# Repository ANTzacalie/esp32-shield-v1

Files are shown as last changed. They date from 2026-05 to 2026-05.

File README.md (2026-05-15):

# ESP32 Shield V1






---

## About the Project

A **student electronics project** — a large, spacious development shield designed to make working with ESP32 reliable, practical, and accessible. Whether you're prototyping, learning, or building something more permanent, this board gives you the room and connectivity to do it right.

The ESP32 Shield V1 breaks out **all useful GPIO pins** (bootstrapping pins like GPIO11 excluded) through both **terminal block connectors** for permanent wiring and **male pin headers** for Dupont jumper wire access. It supports both the **ESP32 DevKit C** and **ESP32-S** variants — both fit into the onboard 2×19 socket pins.

Power is supplied through a modern **USB-C 6-pin connector**, compatible with any USB-C charger or USB-A to USB-C adapter — no more bulky legacy connectors. A **power LED** confirms the board is live at a glance.

---

## Features

-  **USB-C Power Input** — 6-pin USB-C connector; works with any USB-C or USB-A (female-to-USB-C) charger
-  **Full GPIO Breakout** — all useful ESP32 GPIO pins exposed (bootstrapping pins excluded)
-  **Terminal Block Connectors** — for all useful pins, ideal for permanent or semi-permanent wiring
-  **Male Pin Headers** — Dupont-compatible, for quick breadboard or jumper wire access
-  **ESP32 DevKit C & 32S Compatible** — both modules fit the 2×19 socket pin layout
-  **5V Rail up to 1A** — 2 terminal blocks with 5V and GND in 1:1 configuration
-  **5V & 3.3V Header Pins** — 2×4 header for 5V and 3.3V (max 500mA via AMS1117-3.3 regulator)
-  **4×4 GND Header** — dedicated ground header block
-  **Power Indicator LED** — shows board is powered and ready
-  **Big, Spacious Board** — generous layout for comfortable hand soldering and clear wiring

---

## Gallery

<p align="center">
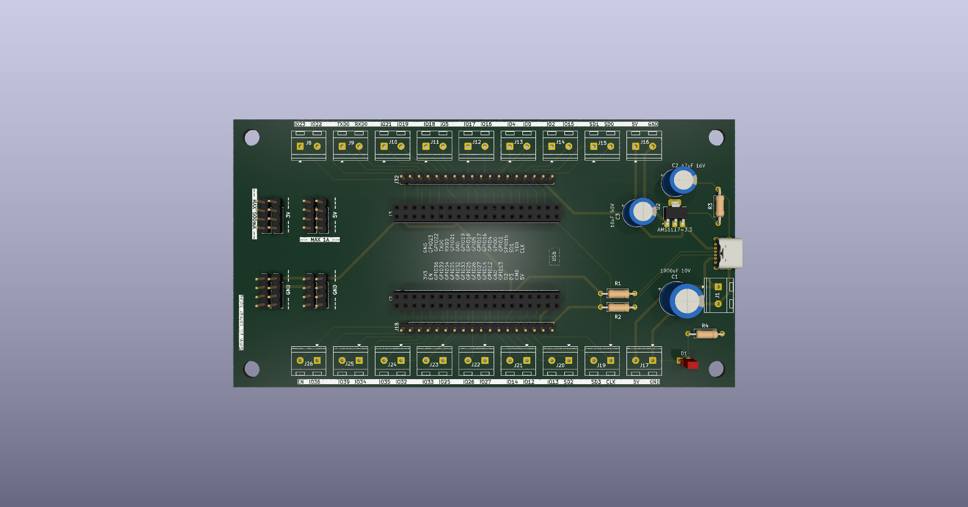
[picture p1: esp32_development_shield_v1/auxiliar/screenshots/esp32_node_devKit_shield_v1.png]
  
  &nbsp;&nbsp;
  
</p>

---

## Documents

| Document | Link |
|---|---|
| PCB Layout | [shield_v1_pcb.pdf](esp32_development_shield_v1/auxiliar/screenshots/shield_v1_pcb.pdf) |
| Schematic | [shield_v1_schematic.pdf](esp32_development_shield_v1/auxiliar/screenshots/shield_v1_schematic.pdf) |

---

## Demo

<p align="center">
  ESP32 Shield V1 Demo
  <!-- If using mp4: see auxiliar/test_video/video.mp4 -->
</p>

---

## Folder Structure

```
esp32-shield-v1/
│
├── auxiliar/
│   ├── compatibility_info/       # Compatibility notes for ESP32 variants
│   ├── screenshots/              # Board photos (photo1–photo4)
│   └── test_video/               # Demo video (video.gif / video.mp4)
│
├── pcb/
│   ├── bom_files/                # 📋 Bill of Materials (BOM)
│   ├── drill_files/              # 🔩 Drill files for PCB fabrication
│   └── gerber_files/             # 📦 Gerber files — send these to your PCB fab
│
└── schematic/
    ├── esp32_node_devkit_shield_v1/   # Main schematic project files
    └── symbols&footprints/            # Custom KiCad symbols and footprints
```

> **PCB fabrication files are located in `/pcb/`:**
> - **`/pcb/gerber_files/`** — Production-ready Gerber files for your PCB manufacturer
> - **`/pcb/drill_files/`** — Drill/Excellon files for hole placement
> - **`/pcb/bom_files/`** — Bill of Materials for component sourcing

---

## Getting Started

1. Clone or download this repository
2. Open the schematic in **KiCad** from `/schematic/esp32_node_devkit_shield_v1/`
3. Review the BOM in `/pcb/bom_files/` and source your components
4. Send the files from `/pcb/gerber_files/` and `/pcb/drill_files/` to your preferred PCB manufacturer
5. Assemble, plug in your ESP32 DevKit C or 32S, connect USB-C power, and build something!

---

## Compatibility

| Module | Fits? |
|---|---|
| ESP32 DevKit C | ✅ Yes |
| ESP32-S (DevKitS) | ✅ Yes |

See `/auxiliar/compatibility_info/` for detailed notes.

---

## Power Specifications

| Rail | Max Current | Connector Type |
|---|---|---|
| 5V | 1A | 2× Terminal Block (5V + GND) |
| 5V | — | 2×4 Pin Header |
| 3.3V | 500mA | 2×4 Pin Header (AMS1117-3.3) |
| GND | — | 4×4 Pin Header |

---

## License

This project is open source. Feel free to use, modify, and build upon it for personal and educational purposes.

---

*Made with monster-energy and a soldering iron — student electronics project*

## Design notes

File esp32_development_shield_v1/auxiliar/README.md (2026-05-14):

///////////////// Components Used /////////////////

- 1 x AMS1117 3.3 Linear Voltage Regulator;
- 18 x Screw_Terminal_Block_1x02_P5mm or 2 x 1x18_P5mm;
- 1 x Screw_Terminal_Block_1x02_P5mm;
- 8 x 1x04 Pin_Header_P2.54mm;
- 2 x 1x18 Pin_Header_P2.54mm;
- 2 x 02x19 or 02x20(break one off) Pin_Socket_P2.54mm;
- 1 x 6 pin USB-C Power Conector;
- 2 x 5.1k resistors;
- 1 x 330 ohm resistor;
- 1 x 220 ohm resistor;
- 1 x 50V 10uF capacitor;
- 1 x 16V 47uF capacitor;
- 1 x 10V 1000uF capacitor;

///////////////// Components Used /////////////////

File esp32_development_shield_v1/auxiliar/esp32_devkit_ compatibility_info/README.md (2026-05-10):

Shield V1 is compatible with the fallowing ESP32 Devkits:
    - ESP32NodeMCU32S 38 Pin variant, smaller PCB.
        by size: W = 22.9mm between pin barrets
    - ESP32NodeMCU DevKit-C 38 Pin variant, bigger PCB with corner holes.
        by size: W = 25.4mm between pin barrets

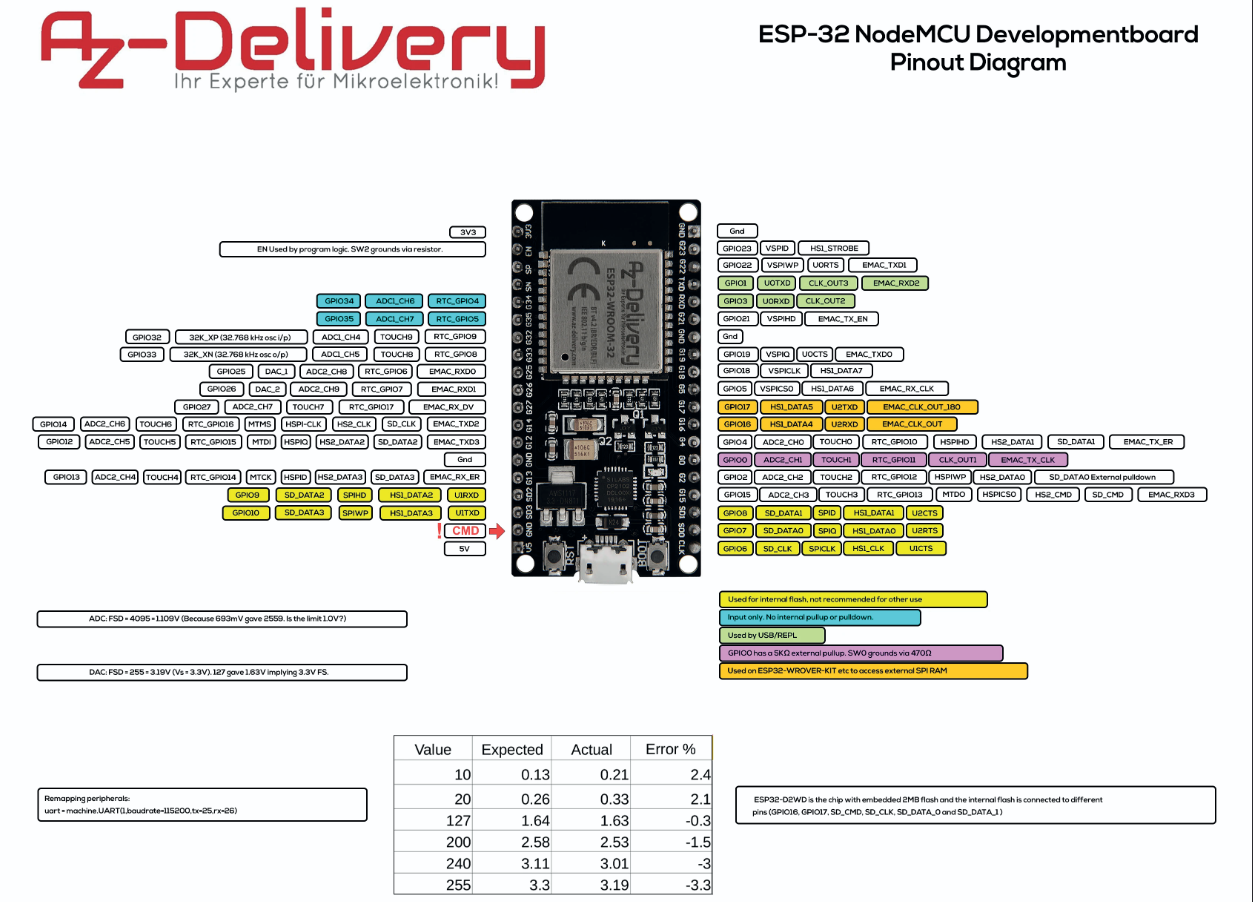
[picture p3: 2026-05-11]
esp32_development_shield_v1/auxiliar/esp32_devkit_ compatibility_info/ESP32-NodeMCU-DevKitM-C.png

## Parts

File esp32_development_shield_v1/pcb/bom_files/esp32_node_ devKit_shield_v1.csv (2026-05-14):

Reference | Qty | Value | DNP | Exclude from BOM | Exclude from Board | Footprint | Datasheet | Description
C1 | 1 | 1000uF 10V |  |  |  | Capacitor_THT:CP_Radial_D10.0mm_P5.00mm |  | Polarized capacitor
C2 | 1 | 47uF 16V |  |  |  | Capacitor_THT:CP_Radial_D8.0mm_P5.00mm |  | Polarized capacitor
C3 | 1 | 10uF 50V |  |  |  | Capacitor_THT:CP_Radial_D8.0mm_P5.00mm |  | Polarized capacitor
D1 | 1 | LED |  |  |  | LED_THT:LED_Rectangular_W3.0mm_H2.0mm |  | Light emitting diode
J1,J8,J9,J10,J11,J12,J13,J14,J15,J16,J17,J19,J20,J21,J22,J23,J24,J25,J26 | 19 | Screw_Terminal_01x02 |  |  |  | TerminalBlock_RND:TerminalBlock_RND_205-00232_1x02_P5.08mm_Horizontal |  | Generic screw terminal, single row, 01x02, script generated (kicad-library-utils/schlib/autogen/connector/)
J2,J3 | 2 | Conn_02x19_Odd_Even |  |  |  | Connector_PinSocket_2.54mm:PinSocket_2x19_P2.54mm_Vertical |  | Generic connector, double row, 02x19, odd/even pin numbering scheme (row 1 odd numbers, row 2 even numbers), script generated (kicad-library-utils/schlib/autogen/connector/)
J4,J5,J6,J7,J27,J28,J29,J30 | 8 | Conn_01x04 |  |  |  | Connector_PinHeader_2.54mm:PinHeader_1x04_P2.54mm_Vertical |  | Generic connector, single row, 01x04, script generated (kicad-library-utils/schlib/autogen/connector/)
J18,J32 | 2 | Conn_01x18_Pin |  |  |  | Connector_PinHeader_2.54mm:PinHeader_1x18_P2.54mm_Vertical |  | Generic connector, single row, 01x18, script generated
J31 | 1 | USB_C_Receptacle_PowerOnly_6P |  |  |  | Connector_USB:USB_C_Receptacle_GCT_USB4125-xx-x_6P_TopMnt_Horizontal | https://www.usb.org/sites/default/files/documents/usb_type-c.zip | USB Power-Only 6P Type-C Receptacle connector
R1,R2 | 2 | 5.1k |  |  |  | Resistor_THT:R_Axial_DIN0207_L6.3mm_D2.5mm_P10.16mm_Horizontal |  | Resistor
R3 | 1 | 330 |  |  |  | Resistor_THT:R_Axial_DIN0207_L6.3mm_D2.5mm_P10.16mm_Horizontal |  | Resistor
R4 | 1 | 220 |  |  |  | Resistor_THT:R_Axial_DIN0207_L6.3mm_D2.5mm_P10.16mm_Horizontal |  | Resistor
U2 | 1 | AMS1117-3.3 |  |  |  | Package_TO_SOT_SMD:SOT-223-3_TabPin2 | http://www.advanced-monolithic.com/pdf/ds1117.pdf | 1A Low Dropout regulator, positive, 3.3V fixed output, SOT-223

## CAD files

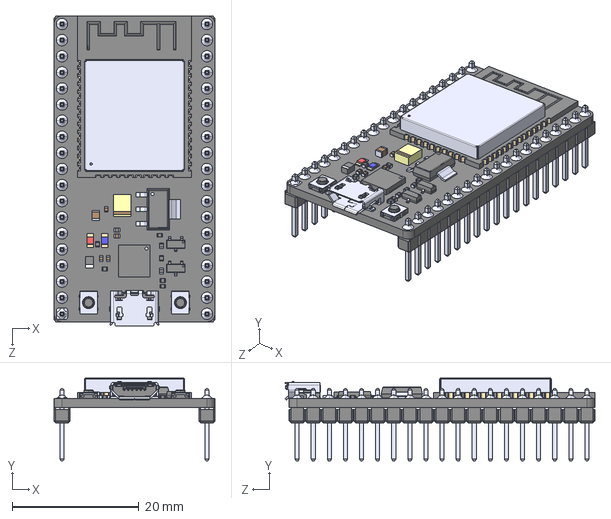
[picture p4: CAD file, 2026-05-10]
esp32_development_shield_v1/schematic/symbols&footprints/ESP-NODEMCU-ESP32S/NODEMCU-ESP32S--3DModel-STEP-269445.STEP
25.4 x 13.0 x 48.9 mm

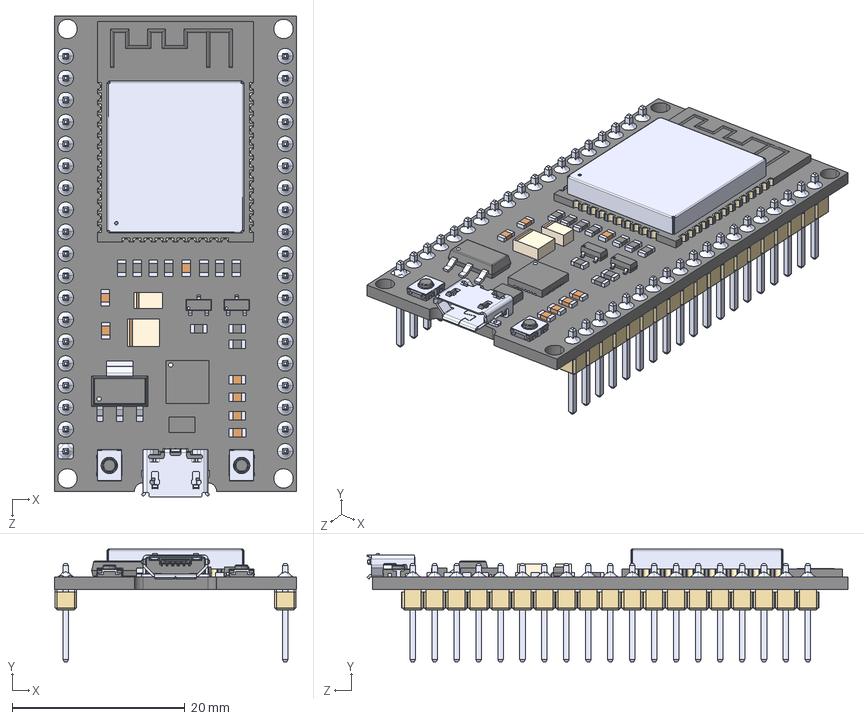
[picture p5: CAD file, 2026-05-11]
esp32_development_shield_v1/schematic/symbols&footprints/ESP32_NODEMCU_AZ-Delivery/ESP32_NODEMCU.step
28.0 x 13.0 x 55.7 mm
board
header
header_2nd
ESP32
micro usb
button x 2
AMS1117-3.3
CP2102
sot-23-3 x 2
other^ESP32 NodeMCU

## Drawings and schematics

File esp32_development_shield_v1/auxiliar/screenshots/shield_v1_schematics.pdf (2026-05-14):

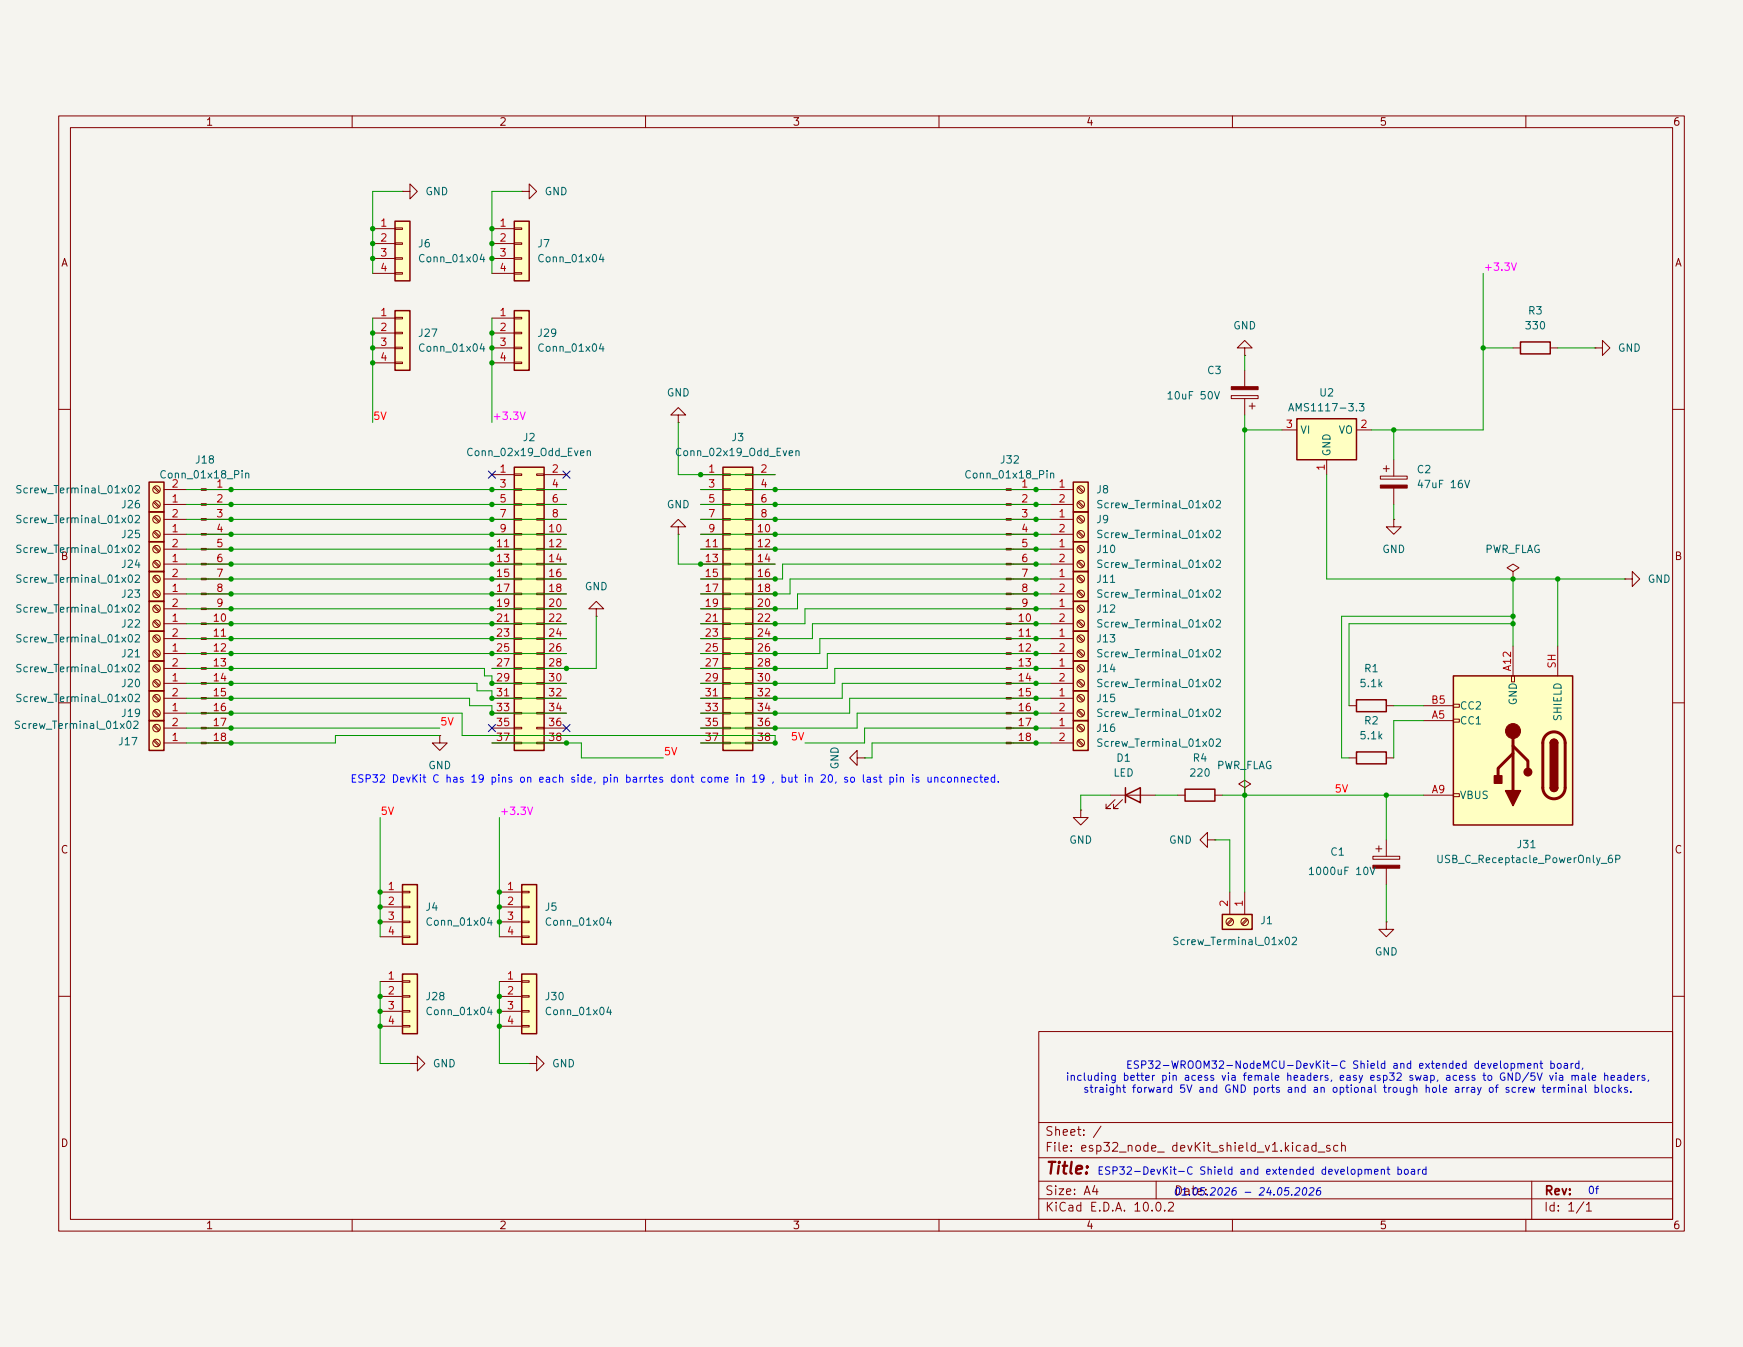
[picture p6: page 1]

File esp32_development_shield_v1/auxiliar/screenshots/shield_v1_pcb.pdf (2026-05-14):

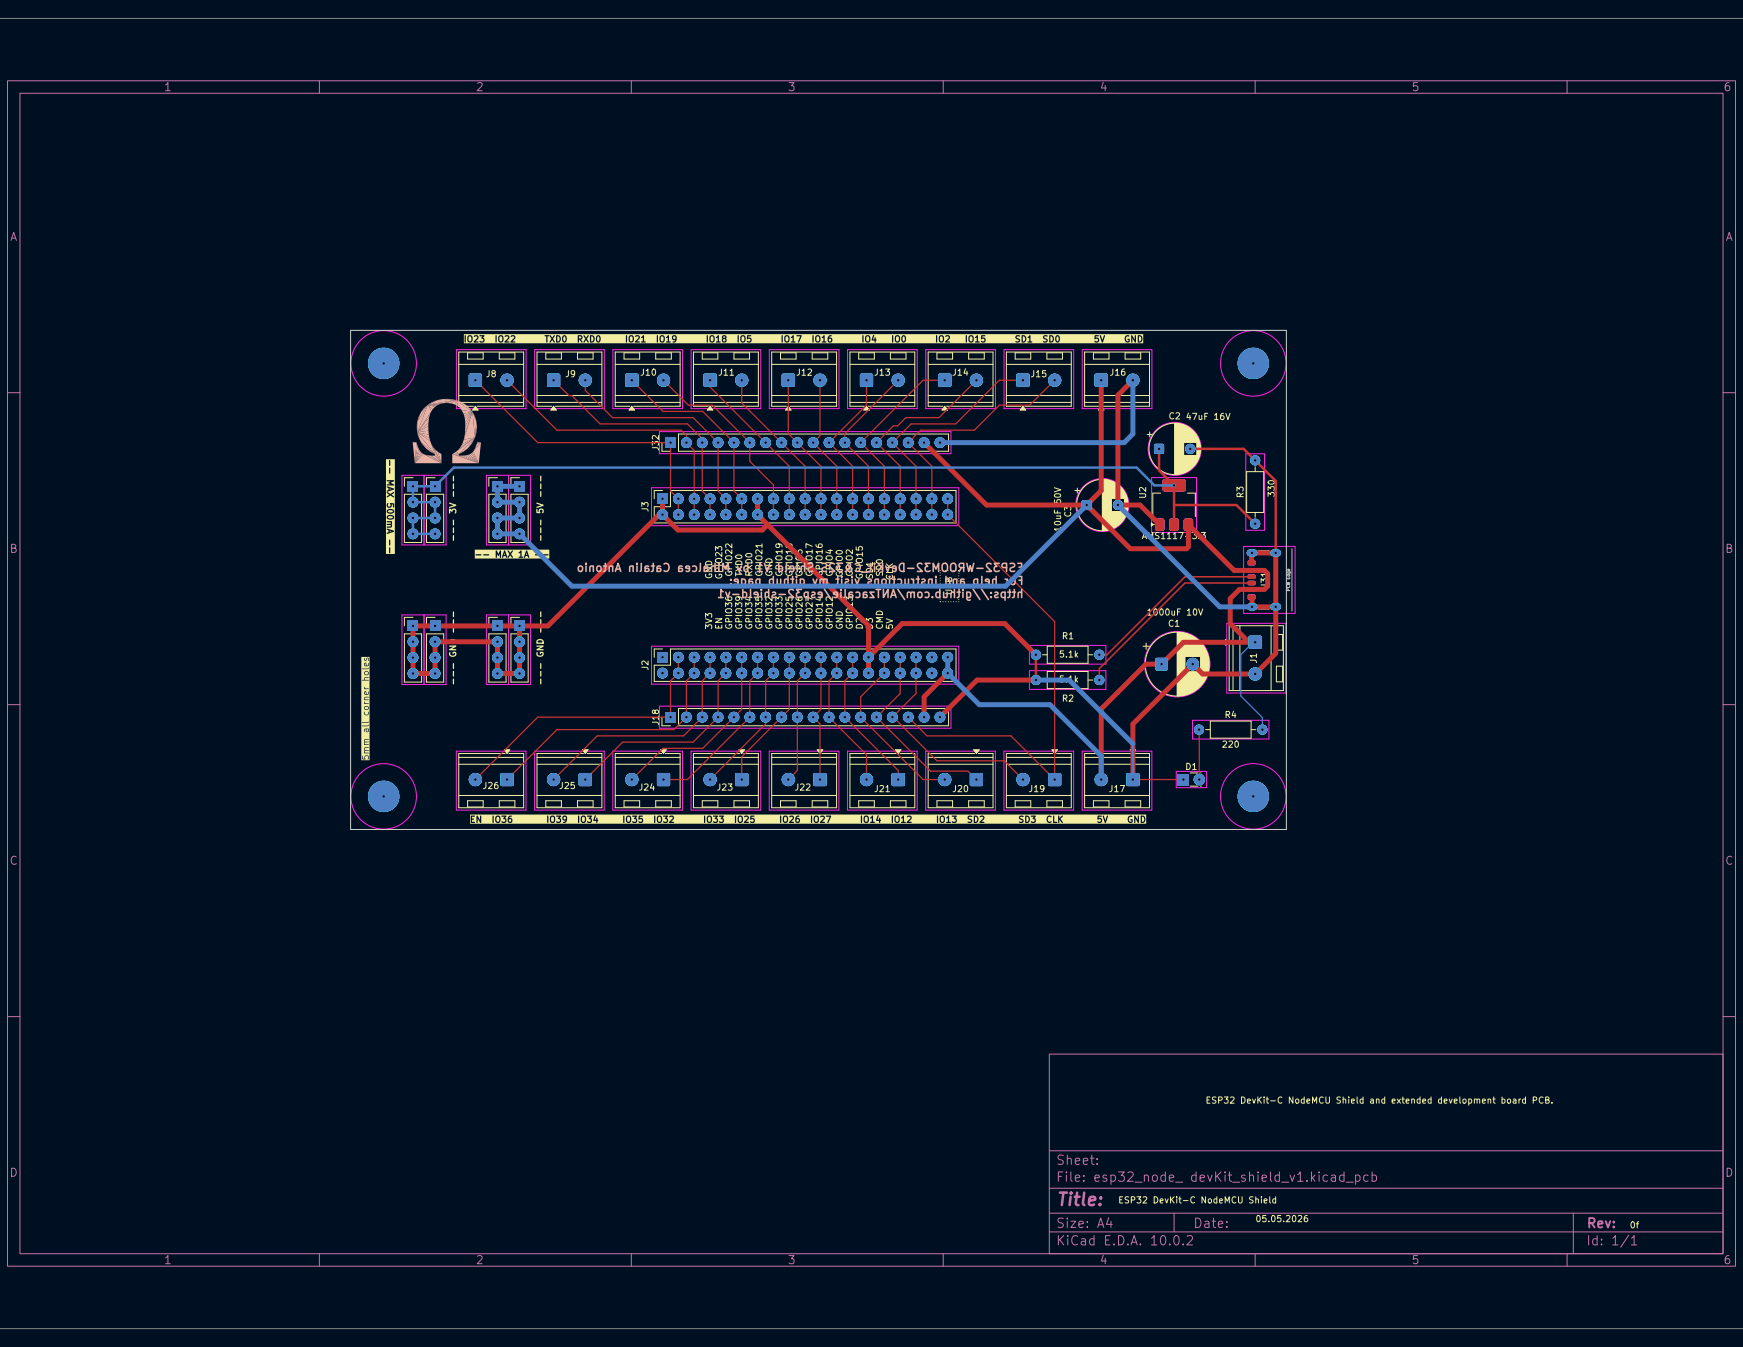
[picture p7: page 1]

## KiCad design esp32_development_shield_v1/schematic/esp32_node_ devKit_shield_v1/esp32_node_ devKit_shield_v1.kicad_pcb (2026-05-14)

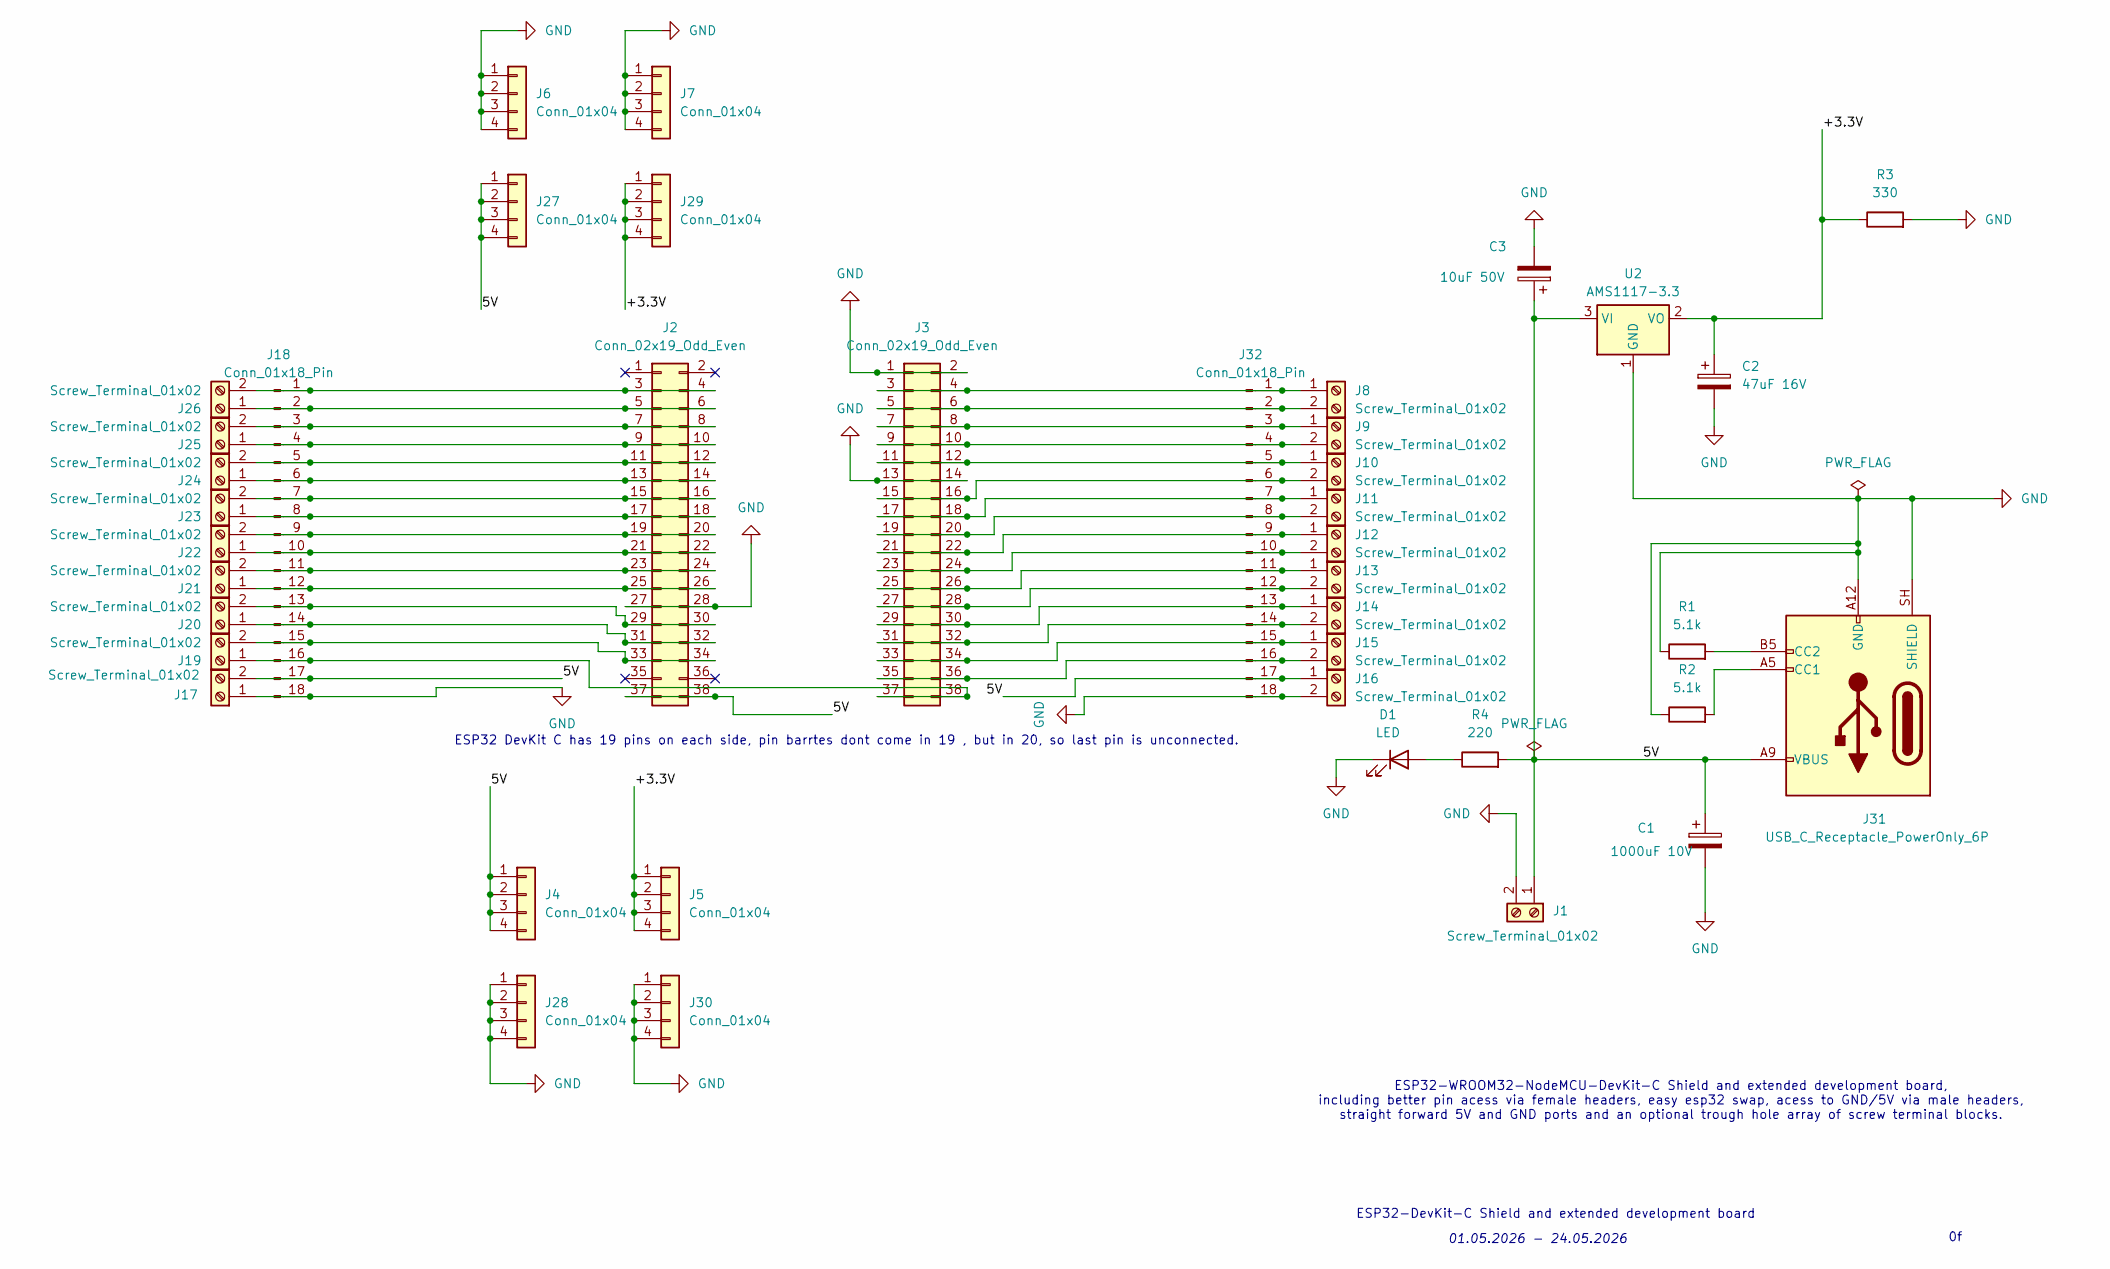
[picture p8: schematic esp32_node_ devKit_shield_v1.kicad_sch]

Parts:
C1: 1000uF 10V; CP_Radial_D10.0mm_P5.00mm
C2: 47uF 16V; CP_Radial_D8.0mm_P5.00mm
C3: 10uF 50V; CP_Radial_D8.0mm_P5.00mm
D1: LED; LED_Rectangular_W3.0mm_H2.0mm
J1, J8, J9, J10, J11, J12, J13, J14, J15, J16, J17, J19, J20, J21, J22, J23, J24, J25, J26: Screw_Terminal_01x02; TerminalBlock_RND_205-00232_1x02_P5.08mm_Horizontal
J2, J3: Conn_02x19_Odd_Even; PinSocket_2x19_P2.54mm_Vertical
J4, J5, J6, J7, J27, J28, J29, J30: Conn_01x04; PinHeader_1x04_P2.54mm_Vertical
J18, J32: Conn_01x18_Pin; PinHeader_1x18_P2.54mm_Vertical
J31: USB_C_Receptacle_PowerOnly_6P; USB_C_Receptacle_GCT_USB4125-xx-x_6P_TopMnt_Horizontal
R1, R2: 5.1k; R_Axial_DIN0207_L6.3mm_D2.5mm_P10.16mm_Horizontal
R3: 330; R_Axial_DIN0207_L6.3mm_D2.5mm_P10.16mm_Horizontal
R4: 220; R_Axial_DIN0207_L6.3mm_D2.5mm_P10.16mm_Horizontal
U2: AMS1117-3.3; SOT-223-3_TabPin2

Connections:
/5V: C1.1, C3.1, J1.1, J2.37, J2.38, J4.1, J4.2, J4.3, J4.4, J16.1, J17.2, J18.17, J27.1, J27.2, J27.3, J27.4, J31.A9 (VBUS), J31.B9 (VBUS), J32.17, R4.2, U2.3 (VI)
/+3.3V: C2.1, J5.1, J5.2, J5.3, J5.4, J29.1, J29.2, J29.3, J29.4, R3.1, U2.2 (VO)
GND: C1.2, C2.2, C3.2, D1.1 (K), J1.2, J2.27, J2.28, J3.1, J3.2, J3.13, J3.14, J6.1, J6.2, J6.3, J6.4, J7.1, J7.2, J7.3, J7.4, J16.2, J17.1, J18.18, J28.1, J28.2, J28.3, J28.4, J30.1, J30.2, J30.3, J30.4, J31.A12 (GND), J31.B12 (GND), J31.SH (SHIELD), J32.18, R1.1, R2.1, R3.2, U2.1 (GND)
unnamed: D1.2 (A), R4.1
unnamed: J3.3, J3.4, J8.1, J32.1
unnamed: J3.5, J3.6, J8.2, J32.2
unnamed: J3.7, J3.8, J9.1, J32.3
unnamed: J3.9, J3.10, J9.2, J32.4
unnamed: J3.11, J3.12, J10.1, J32.5
unnamed: J3.15, J3.16, J10.2, J32.6
unnamed: J3.17, J3.18, J11.1, J32.7
unnamed: J3.19, J3.20, J11.2, J32.8
unnamed: J3.21, J3.22, J12.1, J32.9
unnamed: J3.23, J3.24, J12.2, J32.10
unnamed: J3.25, J3.26, J13.1, J32.11
unnamed: J3.27, J3.28, J13.2, J32.12
unnamed: J3.29, J3.30, J14.1, J32.13
unnamed: J3.31, J3.32, J14.2, J32.14
unnamed: J3.33, J3.34, J15.1, J32.15
unnamed: J3.35, J3.36, J15.2, J32.16
unnamed: J2.3, J2.4, J18.1, J26.2
unnamed: J2.5, J2.6, J18.2, J26.1
unnamed: J2.7, J2.8, J18.3, J25.2
unnamed: J2.9, J2.10, J18.4, J25.1
unnamed: J2.11, J2.12, J18.5, J24.2
unnamed: J2.13, J2.14, J18.6, J24.1
unnamed: J2.15, J2.16, J18.7, J23.2
unnamed: J2.17, J2.18, J18.8, J23.1
unnamed: J2.19, J2.20, J18.9, J22.2
unnamed: J2.21, J2.22, J18.10, J22.1
unnamed: J2.23, J2.24, J18.11, J21.2
unnamed: J2.25, J2.26, J18.12, J21.1
unnamed: J2.29, J2.30, J18.13, J20.2
unnamed: J2.31, J2.32, J18.14, J20.1
unnamed: J2.33, J2.34, J18.15, J19.2
unnamed: J3.37, J3.38, J18.16, J19.1
unnamed: J31.A5 (CC1), R2.2
unnamed: J31.B5 (CC2), R1.2

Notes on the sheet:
ESP32-DevKit-C Shield and extended development board
ESP32-WROOM32-NodeMCU-DevKit-C Shield and extended development board, including better pin acess via female headers, easy esp32 swap, acess to GND/5V via male headers, straight forward 5V and GND ports and an optional trough hole array of screw terminal blocks.
ESP32 DevKit C has 19 pins on each side, pin barrtes dont come in 19 , but in 20, so last pin is unconnected.
01.05.2026 - 24.05.2026

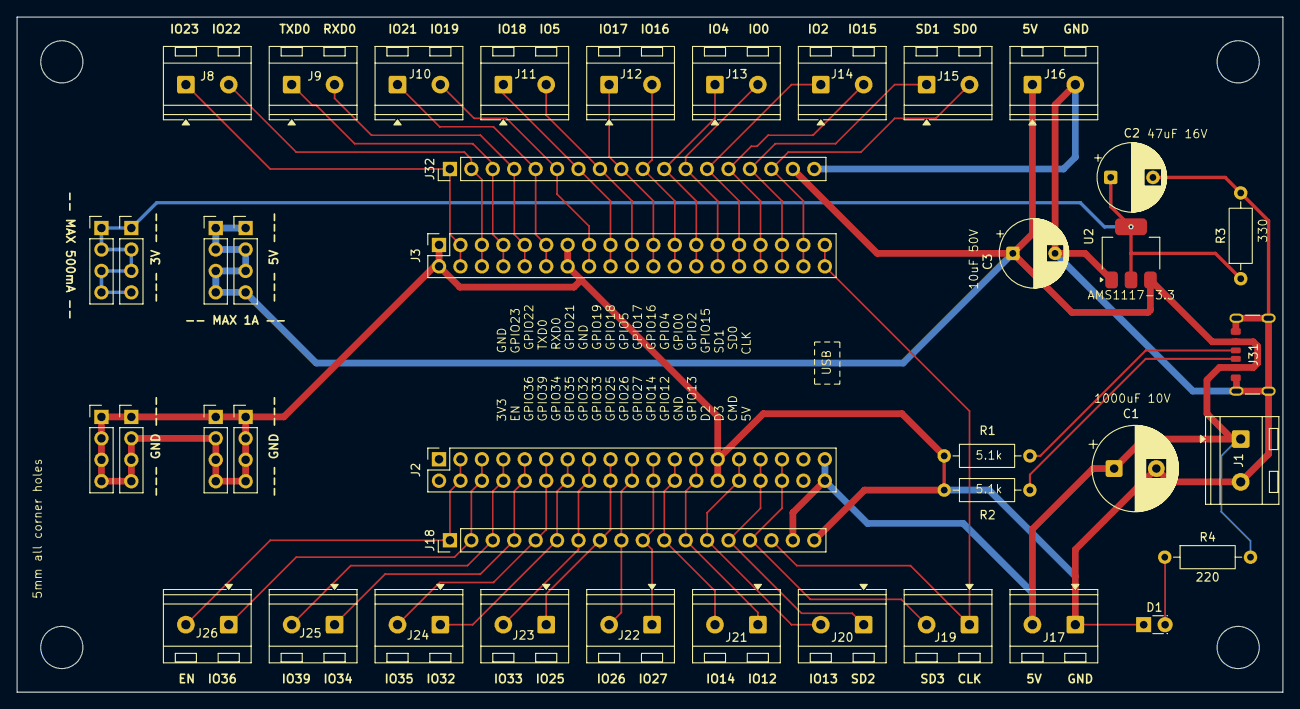
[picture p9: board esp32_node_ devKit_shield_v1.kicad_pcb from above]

Board: 2 copper layers, 150.0 x 80.0 mm, 41 parts (0 on the bottom side), 38 nets.

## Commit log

2026-05-10 ESP32 Devkit Shield V1 finished
    - ESP32 Shield V1 scheme finished.
    - Capacitors for AMS1117 3.3 set.
    - Circuit 1000uF Capacitors used to cover the ESP32 Devkit that requires 550uF, and all other components that are gonna be conected to the 5V and 3.3V pins.
    - Shield PCB completed and inspected, ready for fabrication.
    [ESP32 NodeMCU DevKit Shield V1-B_Cu.gbr, ESP32 NodeMCU DevKit Shield V1-B_Mask.gbr, ESP32 NodeMCU DevKit Shield V1-B_Paste.gbr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]
2026-05-10 folder structure changed
    [ESP32 NodeMCU DevKit Shield V1-B_Cu.gbr, ESP32 NodeMCU DevKit Shield V1-B_Mask.gbr, ESP32 NodeMCU DevKit Shield V1-B_Paste.gbr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]
2026-05-13 *
    Replaced socket with header
    [esp32_node_ devKit_shield_v1-B_Cu.gbr, esp32_node_ devKit_shield_v1-B_Mask.gbr, esp32_node_ devKit_shield_v1-B_Paste.gbr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]
2026-05-14 Added LED for power on/off
    [esp32_node_ devKit_shield_v1-B_Cu.gbr, esp32_node_ devKit_shield_v1-B_Mask.gbr, esp32_node_ devKit_shield_v1-B_Paste.gbr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]
2026-05-14 added components used readme
    [ESP32_NODEMCU.step, NODEMCU-32S.step, NODEMCU-ESP32S--3DModel-STEP-269445.STEP]
2026-05-15 Add README for ESP32 Shield V1 project
    This README provides detailed information about the ESP32 Shield V1 project, including features, gallery, demo, folder structure, getting started instructions, compatibility, power specifications, an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
2026-05-23 PCB.zip files uploaded
    2-5 days until PCB are received
2026-10-23 Photo of the final board
    Shield has been successfully tested and is operational.
2026-10-23 Video proof of the board working
